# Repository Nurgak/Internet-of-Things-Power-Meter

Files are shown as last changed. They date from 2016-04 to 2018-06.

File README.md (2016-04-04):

# Internet-of-Things Power Meter

The Internet-of-Things Power Meter (IPM) is a device fixed on top of the regular household power meter and provides detailed information about the electricity usage. Modern power meters have a LED blinking every time a Watt is used, the IPM detects these flashes using a light sensor, counts them and saves the values to an SD card. Later the data is stored on the cloud.

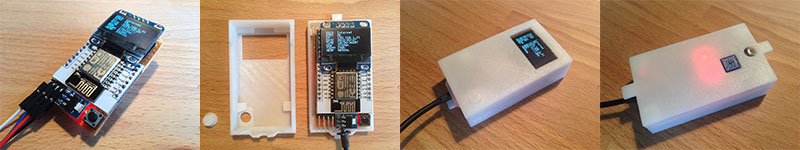
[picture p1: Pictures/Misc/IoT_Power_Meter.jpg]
IoT Power Meter development version on a breadboard


Usually power companies provide very rough electricity usage data, the IPM provides data with a minute resolution. Knowing the household electricity usage allows to extrapolate statistics and can give precise numbers about the costs.

The IPM was made with simplicity of assembly and cost in mind. The device is easy to build, program and cheap to deploy and use. One can basically buy the parts, assemble, program and deploy it without any knowledge about the inner workings, however contribution to the development of this open-source project is welcome and encouraged.

This is the second iteration of the electricity usage monitor project, the [first version can be seen here](https://github.com/Nurgak/Electricity-usage-monitor).

# Documentation

During development the IPM project is [documented on hackaday.io](https://hackaday.io/project/6938-internet-of-things-power-meter).

# License

The software is licensed under [GNU General Public License](https://en.wikipedia.org/wiki/GNU_General_Public_License).

The hardware is licensed under [Creative Commons Attribution-ShareAlike 4.0 International License](http://creativecommons.org/licenses/by-sa/4.0/).



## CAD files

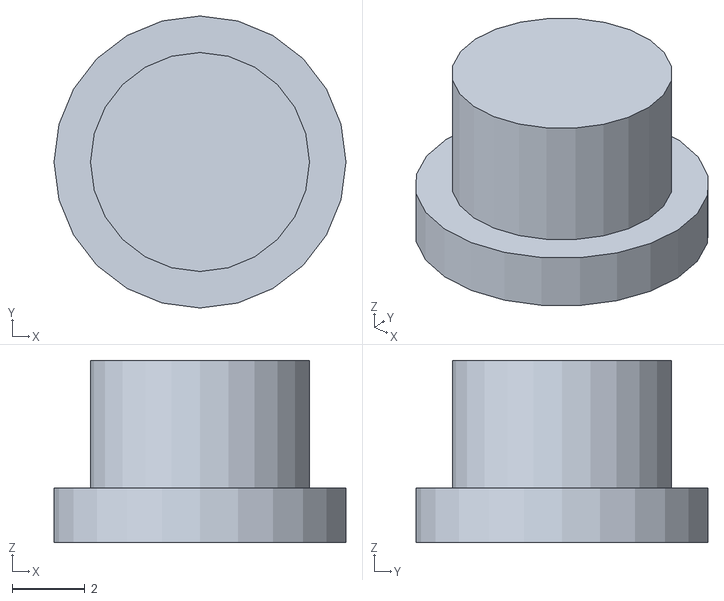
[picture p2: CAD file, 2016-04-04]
Hardware/Enclosure/IPM_Enclosure_button.stl
8.00 x 8.00 x 5.00

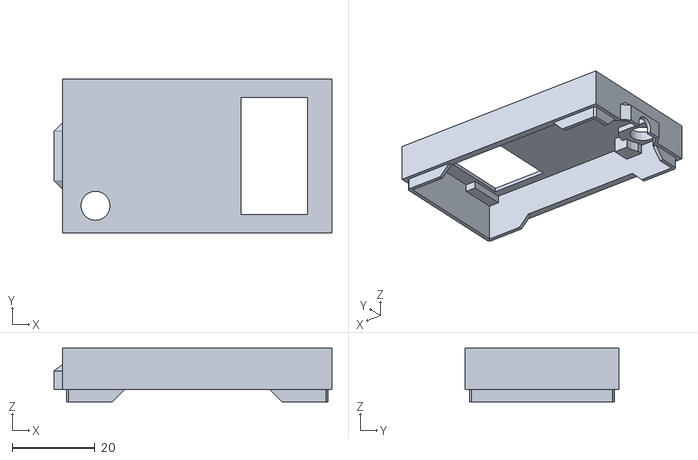
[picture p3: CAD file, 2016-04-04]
Hardware/Enclosure/IPM_Enclosure_top.stl
67.0 x 37.0 x 13.0

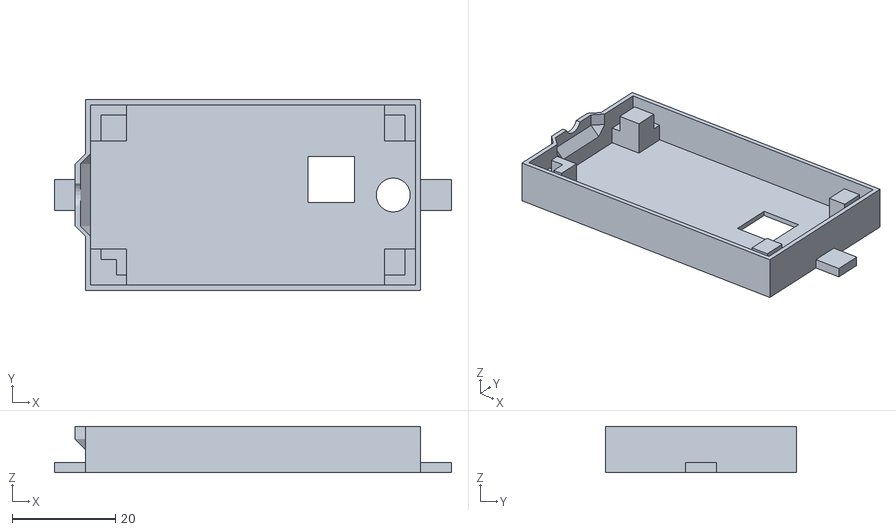
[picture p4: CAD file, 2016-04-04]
Hardware/Enclosure/IPM_Enclosure_bottom.stl
77.0 x 37.0 x 9.00

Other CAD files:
Hardware/Enclosure/IPM_Enclosure.skp

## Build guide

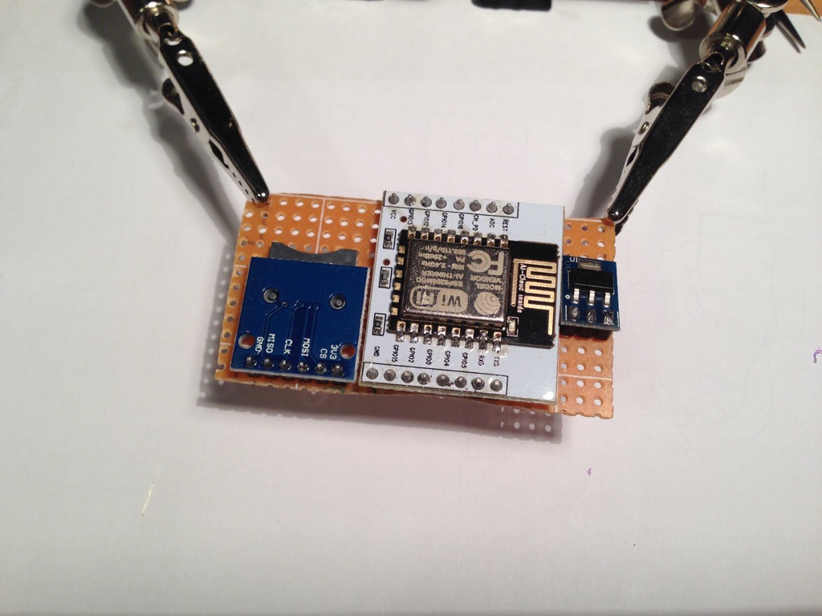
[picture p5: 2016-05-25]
Pictures/Build/2015-12-23 22.54.03.jpg

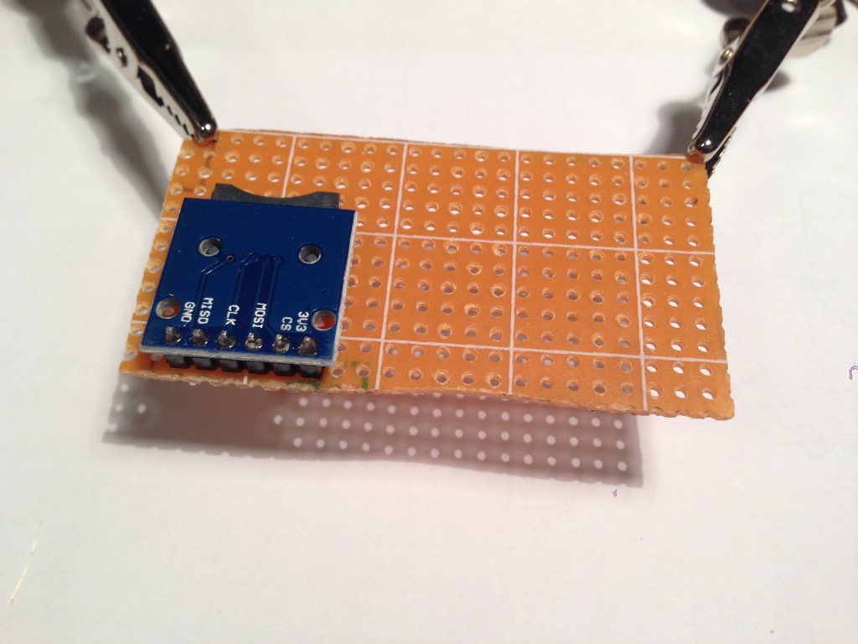
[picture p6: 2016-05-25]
Pictures/Build/2015-12-23 22.53.06.jpg

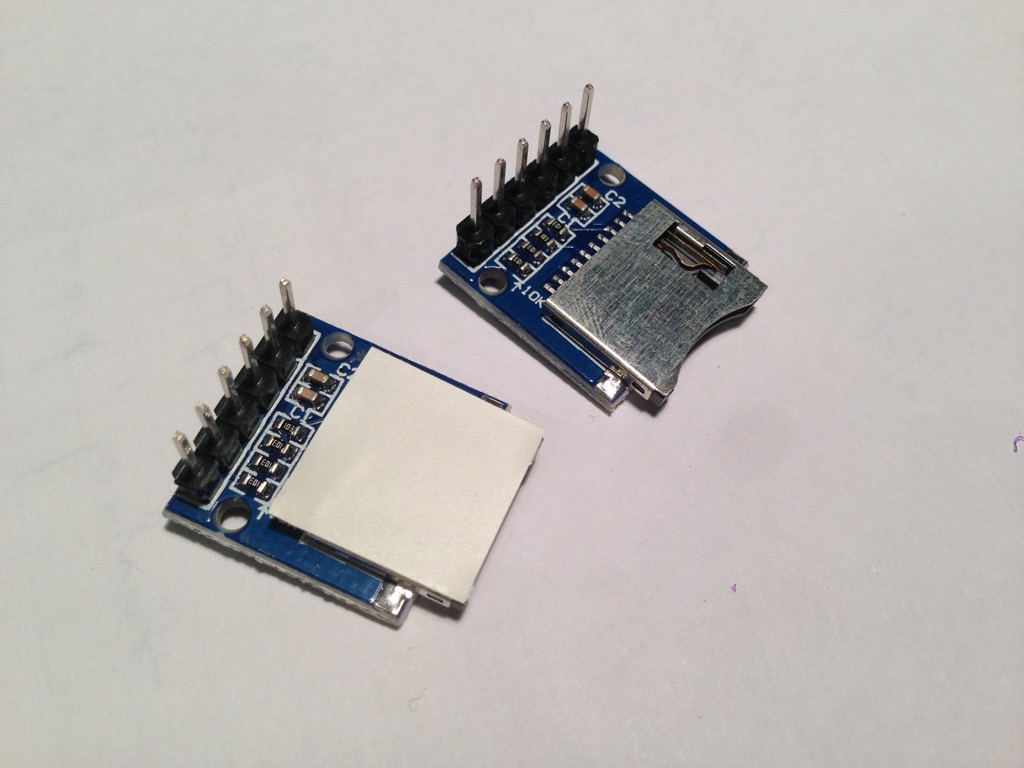
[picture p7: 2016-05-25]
Pictures/Build/2015-12-24 00.51.13.jpg

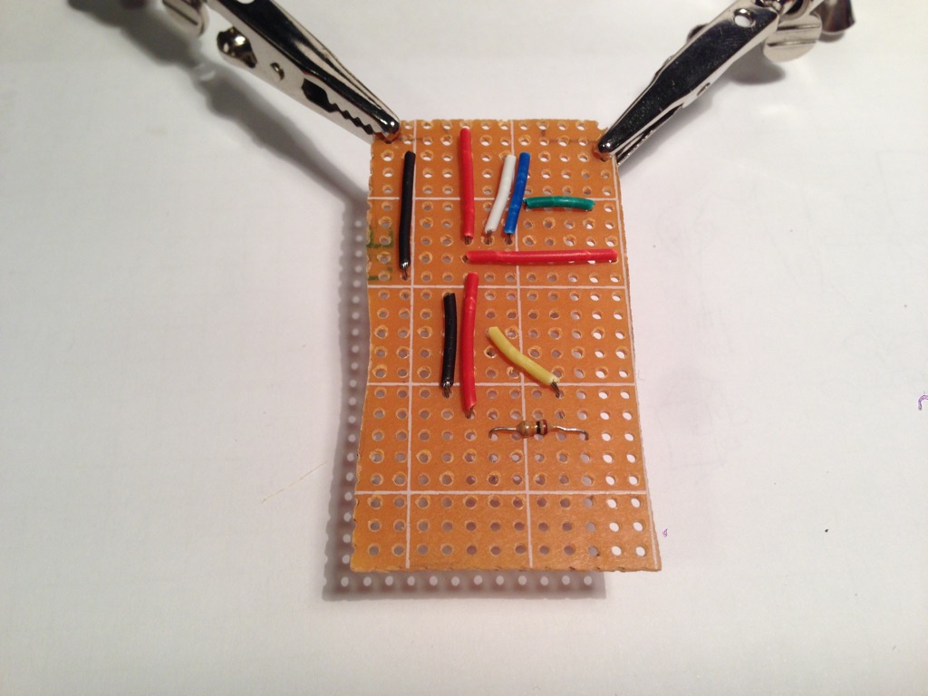
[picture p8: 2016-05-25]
Pictures/Build/2015-12-23 23.28.28.jpg

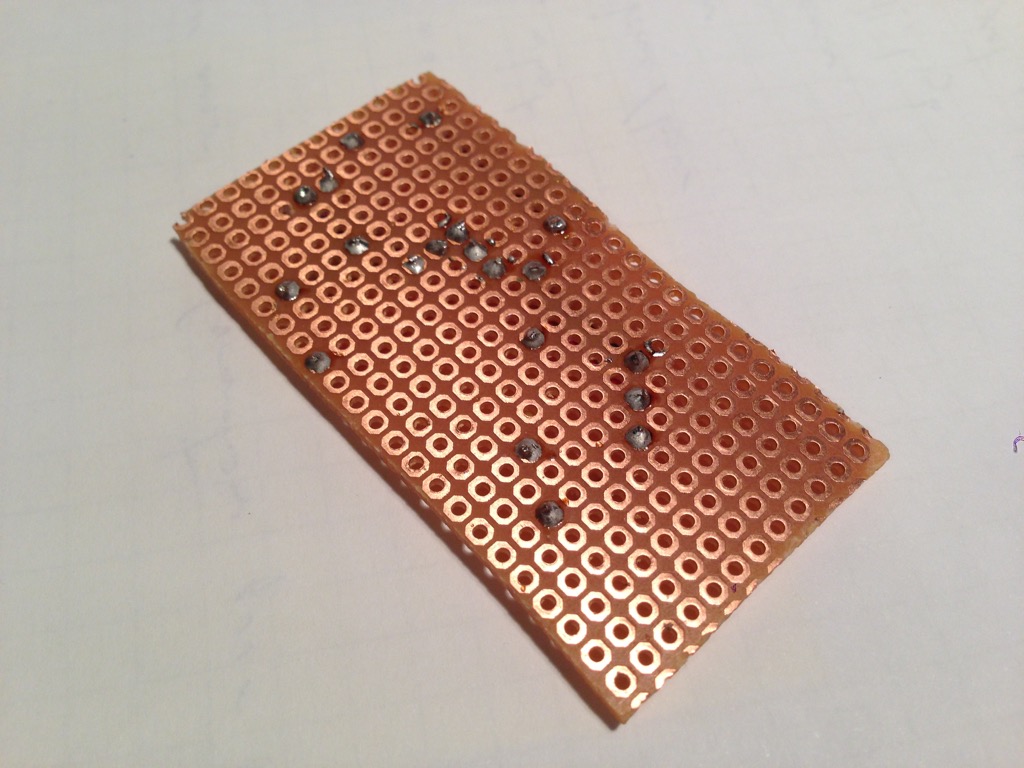
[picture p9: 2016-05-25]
Pictures/Build/2015-12-23 23.42.06.jpg

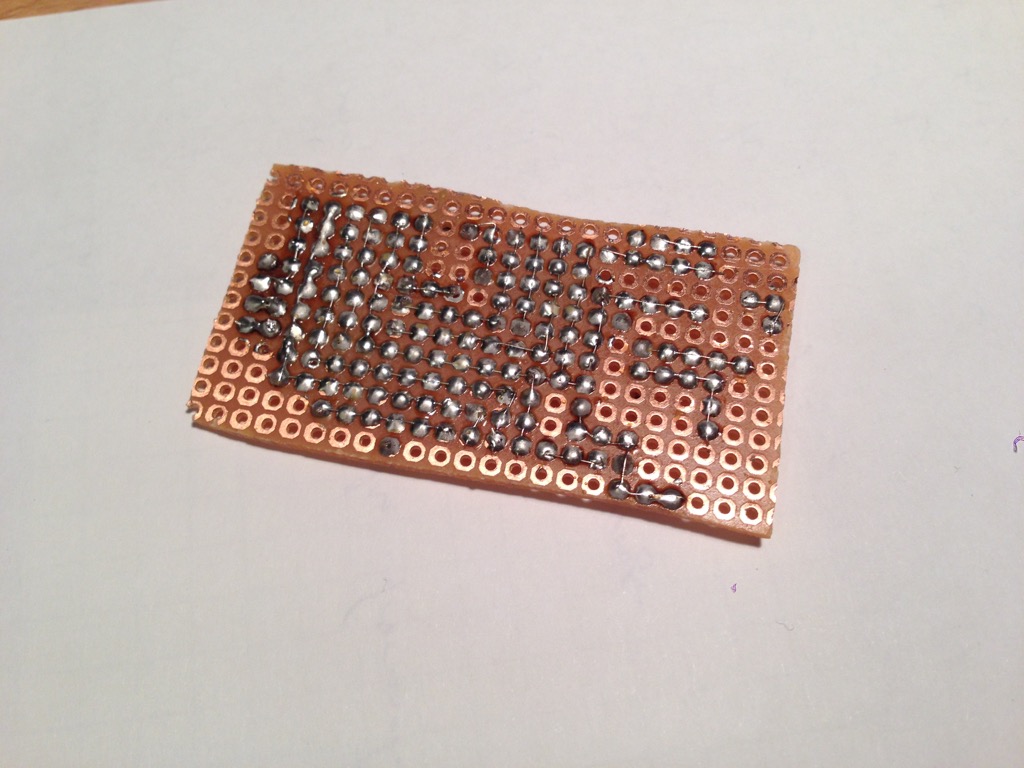
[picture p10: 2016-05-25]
Pictures/Build/2015-12-24 00.49.49.jpg

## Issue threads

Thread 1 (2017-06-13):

Row change in same date

lutfisan, 2017-06-13:
i try your IPM google script, but the row change in same date
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

this is my code
```
// Spreadsheet that is holding all the data
var SPREADSHEET_ID = "****";
var TIMEZONE = "Asia/Jakarta";
// Daylight savings time is not applied when this form is used:
//var TIMEZONE = "GMT+1";
// Secret token to make sure nobody else can submit data, even if the URL is disclosed
var TOKEN = "aku";

function doGet(e)
{
  return handleResponse(e);
}

function doPost(e)
{
  return handleResponse(e);
}

function handleResponse(e)
{
  // Extract the GET paramaters
  var data = e.parameter;
  // Dummy data for testing
  //var data = {"time": "1464339114", "power": "1234", "token": "SECRET_TOKEN"};

  // Make sure all data is passed
  if(!data.time || !data.power || !data.token)
  //if(!data.time || !data.power)
  {
    return ContentService.createTextOutput("Missing data");
  }

  // Make sure the data is valid, only numbers for time and power and only characters [a-zA-Z_0-9] for the token
  if(!data.time.match(/^\d+$/) || !data.power.match(/^\d+$/) || !data.token.match(/^\w+$/))
  //if(!data.time.match(/^\d+$/) || !data.power.match(/^\d+$/))
  {
    return ContentService.createTextOutput("Incorrect data");
  }

  // Make sure the token corresponds
  if(data.token != TOKEN)
  {
    return ContentService.createTextOutput("Wrong token");
  }

  var spreadsheet = getSpreadsheet(SPREADSHEET_ID);
  if(!spreadsheet)
  {
    return ContentService.createTextOutput("Spreadsheet not found");
  }

  // Open the day sheet
  var sheetDay = getSheet(spreadsheet, "Day");
  if(!sheetDay)
  {
    return ContentService.createTextOutput("Sheet not found");
  }

  insertData(sheetDay, data.time, data.power);

  return HtmlService.createHtmlOutput("OK");
}

function getSpreadsheet(id)
{
  // Open the spreadsheet
  var spreadsheet = SpreadsheetApp.openById(id);

  // Check that we got a spreadsheet
  if(!spreadsheet)
  {
    return false;
  }

  return spreadsheet;
}

function getSheet(spreadsheet, name)
{
  // Open the sheet
  var sheetDay = spreadsheet.getSheetByName(name);

  // Check that we got a sheet
  if(!sheetDay)
  {
    return false;
  }

  return sheetDay;
}

function insertData(sheet, timeUnix, power)
{
  // Column IDs
  var columnNames = {"date": 1, "power": 2, "cost": 3, "data": 4};

  // Time is passed in UNIX timestamp format in seconds, JavaScript wants milliseconds
  var date = new Date(timeUnix * 1000);

  // This allows to get the local time with timezone and DST
  var dateFormatted = Utilities.formatDate(date, TIMEZONE, "yyyy-MM-dd");
  // Make the hours an actual integer
  var hourFormatted = parseInt(Utilities.formatDate(date, TIMEZONE, "H"));

  // Define an invalid row number
  var rowId = -1;

  // Start from the row after the header (frozen rows)
  var startRow = sheet.getFrozenRows() + 1;

  // Check if there is already a row with the given date, skip the top header rows
  var days = sheet.getRange('A' + startRow +':A').getValues();

  for(var i in days)
  {
    // If the cell is empty then there is no point to go on
    if(days[i] == "")
    {
      // Stop scanning all the empty rows
      break;
    }

    // If the date matches then use that row
    // Use the "yyyy-MM-dd" format as parsing day month and year made it update the wrong day when the day changed for some reason
    // The timezone variable does not matter for a date parsed from "yyyy-MM-dd" format
    var dayFormatted = Utilities.formatDate(new Date(days[i]), 0, "yyyy-MM-dd");

    if(dateFormatted == dayFormatted)
    {
      // Skip the header row
      rowId = parseInt(i) + startRow;
      break;
    }
  }

  // No row with the same date was found
  if(rowId == -1)
  {
    // Since getLastRow() returns the value of the last non-empty row the value has to be increased manually (+1)
    rowId = sheet.getLastRow() + 1;

    // Update the date cell
    sheet.getRange(rowId, columnNames.date).setValue(dateFormatted);

    // Update sum formula for the total day power usage
    sheet.getRange(rowId, columnNames.power).setFormula("=SUM(D" + rowId + ":" + rowId + ")");

    // If there are at least 7 days of data (minus the header row) the settings of the cells one week ago will be copied over (cost formula and background color)
    if(rowId - 7 > sheet.getFrozenRows())
    {
      // Update the cost formula using 7 rows before it (to get the same weekday) if it is a valid cell
      var cost = sheet.getRange(rowId - 7, columnNames.cost).getFormulaR1C1();
      sheet.getRange(rowId, columnNames.cost).setFormulaR1C1(cost);

      // Update the cell formatting (background color) using 7 rows before it
      var backgrounds = sheet.getRange(rowId - 7, columnNames.data, 1, 24).getBackgrounds();
      sheet.getRange(rowId, columnNames.data, 1, 24).setBackgrounds(backgrounds);
    }
  }

  // Only fill the cell when there is nothing in it, otherwise it might overwrite important data
  var cell = sheet.getRange(rowId, columnNames.data + hourFormatted);
  if(cell.getValue() == "")
  {
    cell.setValue(power);
  }
}

```

Nurgak, 2017-09-10:
Sorry for the late answer, the code might be a bit rough as I didn't take care of the edge cases that well. Try adding more than 7 rows and then running it again. Consider contributing fixes if you can.

Closed 2018-05-24.

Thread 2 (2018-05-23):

Refactoring with Node-RED and MQTT

c0zm0z, 2018-05-23:
Hello Nurgak,

i have testet your old IPM. I love how you write code.

Is there any updated code for "Refactoring with Node-RED and MQTT"
I am very interested in in. i have some small MQTT experience, but i have never used Node-RED before. It looks interesting.

Nurgak, 2018-06-02:
@c0zm0z I uploaded the MQTT version: https://github.com/Nurgak/Internet-of-Things-Power-Meter/tree/master/Software/IoTPowerMeterMQTT

Node-RED is something that can really tie everything together. Now I log the data in the Node-RED server instead of the device SD card (less parts and not risking of running out of space) or remotely to Google Spreadsheets. This ensures that even if there is no access to the internet the data is saved.

I've made another project that shows the power consumption thanks to Node-RED: https://github.com/Nurgak/IoT-RGB-LED-Matrix

dony71, 2019-02-01:
I read your article about node-red and mqtt below but don't understand how you create calculation in node-red
Would you mind to share how you configure this in node-red?
I couldn't find also icon output "instant power", "cost", etc

https://hackaday.io/project/6938-internet-of-things-power-meter/log/66881-refactoring-with-node-red-
and-mqtt

Nurgak, 2019-02-02:
@dony71 The instant power is not calculated, you need to subscribe to the relevant MQTT topic. In the case of instant power the MQTT topic is defined as "powerCounterNow":
https://github.com/Nurgak/Internet-of-Things-Power-Meter/blob/e39c132d896e99e5e8b9e577e6842b63cb67a39d/Software/IoTPowerMeterMQTT/IoTPowerMeterMQTT.ino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

The "mqtt in" node configuration would look like this:
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

As far as the cost calculator goes I cannot really help, it depends on your provider tariffs and the model you have. In my case there is a _full price_ and _low price_ depending on the hour of the day and if it's a week-end. That makes a long function that is only relevant to me. Basically all I do it multiply the power cost by the instant usage and I get the instant cents/hour number, nothing really fancy.

dony71, 2019-02-03:
how about others like "power usage the last minute", "power usage the last hour", total "power usage over the day" ?
also i notice there is function extract power for each of them? what is this function equation?

Closed 2018-06-02.

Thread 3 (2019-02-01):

compilation error

dony71, 2019-02-01:
for the software, I follow this link  below
https://hackaday.io/project/6938-internet-of-things-power-meter/log/35131-show-me-the-source-code

while compile, I have this error below
I'm new in this, any step I'm missing?

WARNING: Category 'LED' in library CHT16K33 LED Matrix Library is not valid. Setting to 'Uncategorized'
WARNING: Category 'Input' in library MechInputs is not valid. Setting to 'Uncategorized'
WARNING: Category 'Input' in library SerialSensors is not valid. Setting to 'Uncategorized'
Build options changed, rebuilding all
F:\Users\xxx\Documents\GitHub\Internet-of-Things-Power-Meter\Software\IoTPowerMeter\IoTPowerMeter.ino:32:21: fatal error: TimeLib.h: No such file or directory
 #include <TimeLib.h>
                     ^
compilation terminated.

dony71, 2019-02-01:
i manage to get "timelib.h" from here https://github.com/PaulStoffregen/Time/blob/master/TimeLib.h
compiled OK

Closed 2019-02-01.

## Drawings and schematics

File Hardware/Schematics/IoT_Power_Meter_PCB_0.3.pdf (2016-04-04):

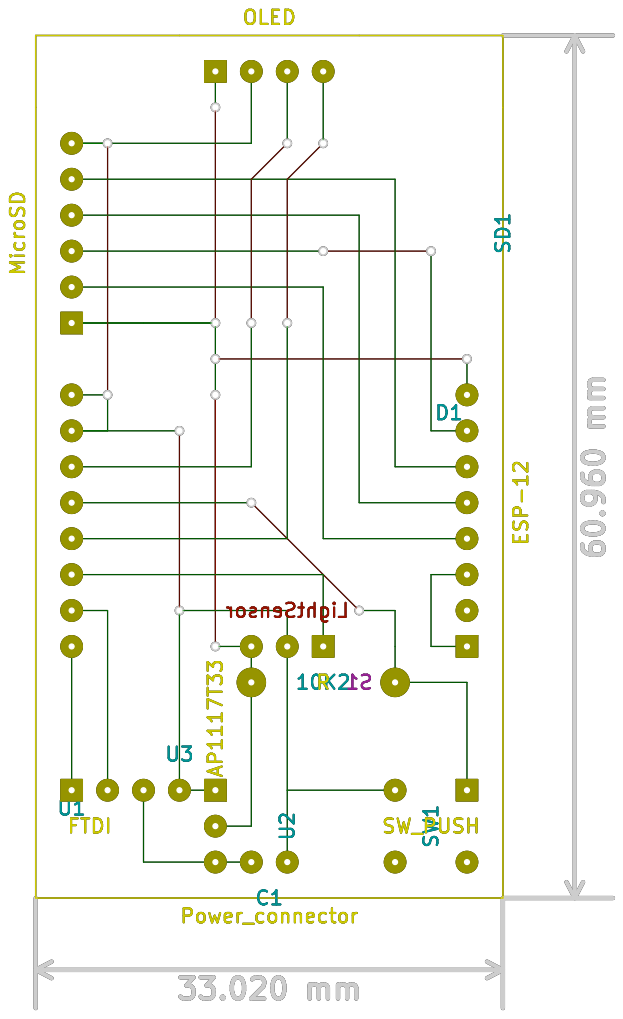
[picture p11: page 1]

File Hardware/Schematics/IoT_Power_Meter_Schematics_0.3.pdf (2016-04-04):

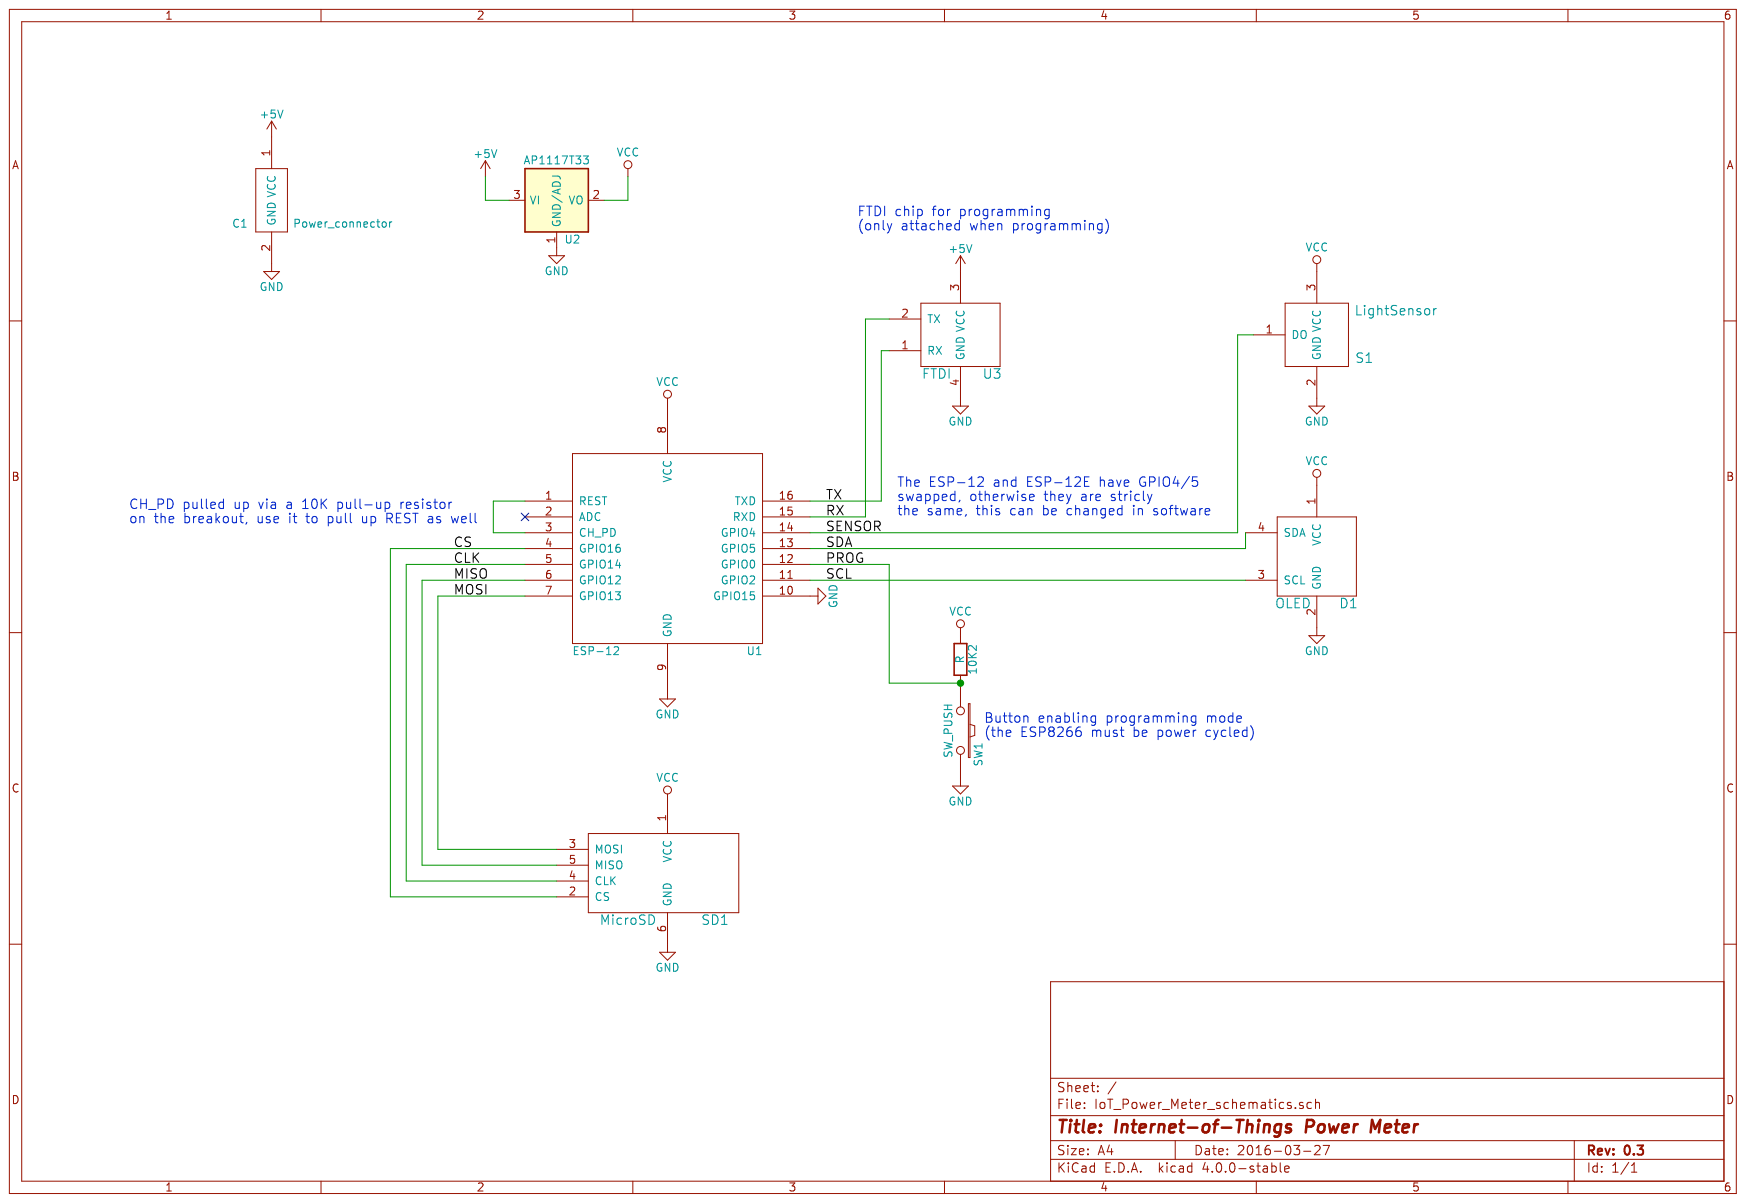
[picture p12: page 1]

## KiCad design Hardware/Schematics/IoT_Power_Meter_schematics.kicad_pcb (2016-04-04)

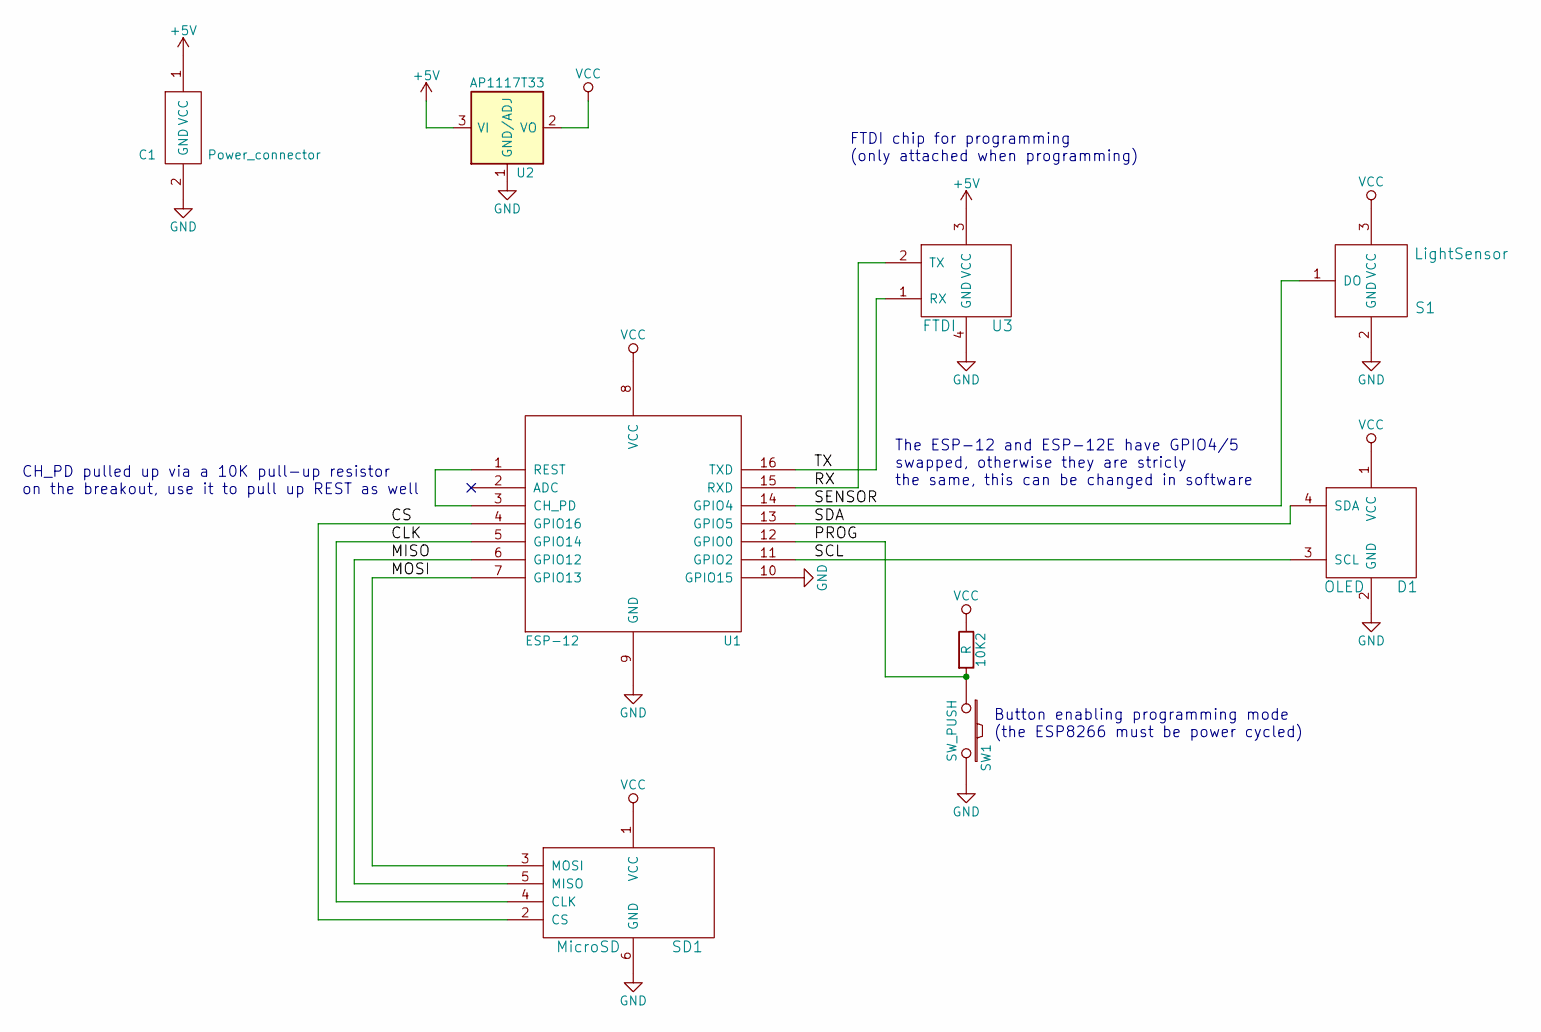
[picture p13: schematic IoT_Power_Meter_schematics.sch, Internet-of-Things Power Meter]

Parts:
10K2: R; Resistor_Horizontal_RM10mm
C1: Power_connector
D1: OLED
S1: LightSensor
SD1: MicroSD; uSD_card_reader
SW1: SW_PUSH; Button
U1: ESP-12; ESP8266-12E_breakout
U2: AP1117T33; 5-3V3_LDO
U3: FTDI

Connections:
+5V: C1.1 (VCC), U2.3 (VI), U3.3 (VCC)
/CLK: SD1.4 (CLK), U1.5 (GPIO14)
/CS: SD1.2 (CS), U1.4 (GPIO16)
/MISO: SD1.5 (MISO), U1.6 (GPIO12)
/MOSI: SD1.3 (MOSI), U1.7 (GPIO13)
/PROG: 10K2.2, SW1.1, U1.12 (GPIO0)
/RX: U1.15 (RXD), U3.2 (TX)
/SCL: D1.3 (SCL), U1.11 (GPIO2)
/SDA: D1.4 (SDA), U1.13 (GPIO5)
/SENSOR: S1.1 (DO), U1.14 (GPIO4)
/TX: U1.16 (TXD), U3.1 (RX)
GND: C1.2 (GND), D1.2 (GND), S1.2 (GND), SD1.6 (GND), SW1.2, U1.9 (GND), U1.10 (GPIO15), U2.1 (GND/ADJ), U3.4 (GND)
unnamed: U1.1 (REST), U1.3 (CH_PD)
VCC: 10K2.1, D1.1 (VCC), S1.3 (VCC), SD1.1 (VCC), U1.8 (VCC), U2.2 (VO)

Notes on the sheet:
Button enabling programming mode (the ESP8266 must be power cycled)
FTDI chip for programming (only attached when programming)
CH_PD pulled up via a 10K pull-up resistor on the breakout, use it to pull up REST as well
The ESP-12 and ESP-12E have GPIO4/5 swapped, otherwise they are stricly the same, this can be changed in software

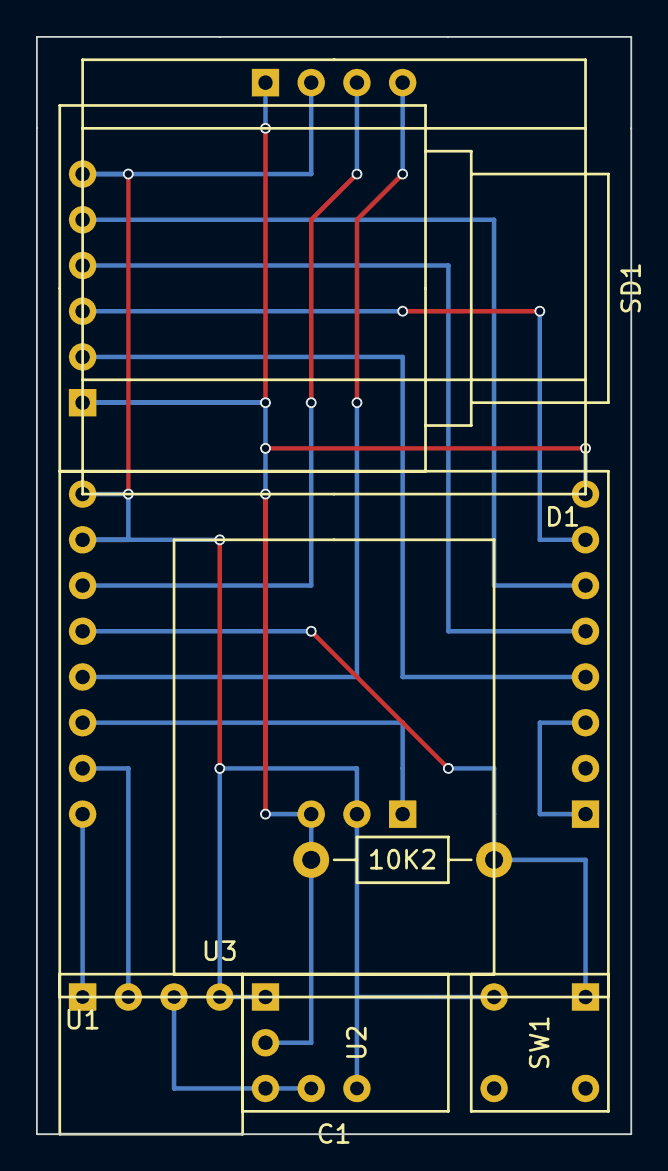
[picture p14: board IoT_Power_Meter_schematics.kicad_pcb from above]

Board: 2 copper layers, 33.0 x 61.0 mm, 9 parts (1 on the bottom side), 14 nets.

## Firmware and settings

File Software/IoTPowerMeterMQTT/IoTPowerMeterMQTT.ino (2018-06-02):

/*
  IoTPowerMeter - Software for the IoTPowerMeter based on the ESP8266

  Copyright (c) 2016 Karl Kangur. All rights reserved.
  This file is part of IoTPowerMeter.

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
  You should have received a copy of the GNU General Public License
  along with IoTPowerMeter.  If not, see <http://www.gnu.org/licenses/>.
*/

/*
 * File:    IoTPowerMeterMQTT.cpp
 * Author:  Karl Kangur <karl.kangur@gmail.com>
 * Licnece: GPL
 * URL:     https://github.com/Nurgak/Internet-of-Things-Power-Meter
 */

#include <ESP8266WiFi.h>
#include <ESP8266mDNS.h>
#include <TimeLib.h>
#include <Wire.h>
#include <ArduinoOTA.h>
#include <PubSubClient.h>

#include "config.h"
#include "IoTPowerMeterMQTT.h"
#include "ESP_SSD1306.h"

// Global instances
ESP_SSD1306 display;
WiFiClient espClient;
PubSubClient client(espClient);

// Global variables
static volatile uint16_t powerCounterMinute = 0;  // Counter used for logs
static volatile uint16_t powerCounterNow    = 0;  // Counter used for display
static volatile uint16_t powerCounterToday  = 0;  // Counter used for display
static volatile uint16_t powerCounterHour   = 0;  // Counter used for upload

// State transition matrix
const transition_t state_transitions[] = {
  {state_wifi_connect,   OK,   state_ota},
  {state_wifi_connect,   BUSY, state_display_update},
  {state_wifi_connect,   FAIL, state_display_update},
  {state_ota,            OK,   state_time_sync},
  {state_time_sync,      OK,   state_mqtt},
  {state_time_sync,      BUSY, state_display_update},
  {state_time_sync,      FAIL, state_display_update},
  {state_mqtt,           OK,   state_log},
  {state_mqtt,           BUSY, state_mqtt},
  {state_log,            OK,   state_display_update},
  {state_log,            BUSY, state_log},
  {state_log,            FAIL, state_display_update},
  {state_display_update, OK,   state_button_check},
  {state_button_check,   OK,   state_wifi_connect}
};

#define START_STATE state_wifi_connect

void setup(void)
{
  // See config.h file to enable/disable debugging
  #ifdef DEBUG_SERIAL
  DEBUG_SERIAL.begin(DEBUG_BAUDRATE);
  DEBUG_SERIAL.setDebugOutput(true);
  #endif

  // Initialise the screen and load a dummy screen
  display.begin();
  display.blank();

  // Define time syncing periodicity
  setSyncInterval(TIME_SYNC_PERIOD);

  // Attach the interrupt that counts the used Watts
  attachInterrupt(SENSOR_PIN, interrupt_blink, FALLING);
  
  // Show the new firmware upload progress on the display in percent
  ArduinoOTA.onProgress([](unsigned int progress, unsigned int total)
  {
    char buffer[16] = {0};
    sprintf(buffer, "Update: %d%%", (100 * progress / total));
    helper_set_status(buffer);
  });

  // Start the Over-The-Air update process
  ArduinoOTA.setHostname(hostName);
  ArduinoOTA.begin();
}

void loop()
{
  // Pointer to current state function, start with wifi connect
  static STATUS (*current_state)(void) = NULL;
  static STATUS code;
  static const size_t transitions = sizeof(state_transitions) / sizeof(state_transitions[0]);
  static size_t i;

  // Run the state machine
  for(i = 0; i < transitions; i++)
  {
    if(state_transitions[i].state_source == current_state && state_transitions[i].code == code)
    {
      current_state = state_transitions[i].state_destination;
      // Call the state function, get the return code back for next transition
      code = (current_state)();
      // Return immediately
      return;
    }
  }

  // Exception: no transition from state was found, start again
  current_state = START_STATE;
}

STATUS ICACHE_FLASH_ATTR state_wifi_connect()
{
  static STATUS wifi_connect_status = FAIL;
  static uint32_t time_wifi_connect = 0;
  static bool wifi_configured = false;

  // If connected and configuration is correct return immediately
  if(wifi_configured && WiFi.status() == WL_CONNECTED)
  {
    if(wifi_connect_status != OK)
    {
      helper_set_status("OK");
      time_wifi_connect = 0;
      
      client.setServer(mqtt_server, mqtt_port);
  
      wifi_connect_status = OK;
    }
  }
  else if(wifi_connect_status == BUSY)
  {
    if(millis() - time_wifi_connect > TIME_WIFI_CONNECT)
    {
      time_wifi_connect = 0;
      wifi_configured = false;
      wifi_connect_status = FAIL;
    }
    else
    {
      wifi_connect_status = BUSY;
    }
  }
  else
  {
    // Calling WiFi.begin disconnects and prevents the module from connecting
    WiFi.begin(wifi_ssid, wifi_password);

    // Without this the WiFi might connect too fast using an old configuration
    wifi_configured = true;

    // Required to get mDNS working
    MDNS.begin(hostName);

    helper_set_status("Connecting");
    time_wifi_connect = millis();
    wifi_connect_status = BUSY;
  }

  return wifi_connect_status;
}

STATUS ICACHE_FLASH_ATTR state_ota()
{
  // Handle OTA updates
  ArduinoOTA.handle();

  // This state can only return true, the particular cases are taken care by OTA
  // callbacks (start, progress, end...) which must be defined in the setup
  return OK;
}

STATUS ICACHE_FLASH_ATTR state_time_sync()
{
  // Internal time sync state
  static STATUS time_sync_status = FAIL;
  static WiFiUDP udp;
  static byte packetBuffer[NTP_PACKET_SIZE] = {0};
  // Time when the request was started
  static uint32_t time_request = 0;

  // Time can be set, unset or in need of synchronisation modes
  if(timeStatus() == timeSet)
  {
    time_sync_status = OK;
  }
  else if(time_sync_status == BUSY)
  {
    if(udp.parsePacket())
    {
      // Read packet to buffer
      udp.read(packetBuffer, NTP_PACKET_SIZE);

      // Only bytes 40 to 43 are important, trash the rest
      // Concatenate 4 bytes and remove 70 years since Unix time starts on Jan 1 1970 and we want 1900
      time_t currentTime = ((packetBuffer[40] << 24) | (packetBuffer[41] << 16) | (packetBuffer[42] << 8) | packetBuffer[43]) - 2208988800UL;
      setTime(currentTime);

      // Stop and release the resources
      udp.stop();
      // Time has been synchronised with server, return OK
      helper_set_status("OK");
      time_request = 0;
      time_sync_status = OK;
    }
    else if(millis() - time_request > TIME_SYNC_RESPONSE)
    {
      // Stop and release the resources
      udp.stop();
      // Waited for too long for time sync
      helper_set_status("Time error");
      time_request = 0;
      time_sync_status = FAIL;
    }
    else
    {
      time_sync_status = BUSY;
    }
  }
  else
  {
    helper_set_status("Time sync");

    // Synchronise local time with an Network Time Protocol (NTP) server
    IPAddress timeServerIP;

    udp.begin(2390);

    // Get the IP from the address
    WiFi.hostByName(ntpServerName, timeServerIP);

    // Send an NTP packet to a time server
    memset(packetBuffer, 0, NTP_PACKET_SIZE);

    packetBuffer[0] = 0b11100011;  // LI, Version, Mode
    packetBuffer[1] = 0;           // Stratum, or type of clock
    packetBuffer[2] = 6;           // Polling Interval
    packetBuffer[3] = 0xEC;        // Peer Clock Precision
    // 8 bytes of zero for Root Delay & Root Dispersion
    packetBuffer[12] = 49;
    packetBuffer[13] = 0x4E;
    packetBuffer[14] = 49;
    packetBuffer[15] = 52;

    // Send the packet to port 123 of the NTP server
    udp.beginPacket(timeServerIP, 123);
    udp.write(packetBuffer, NTP_PACKET_SIZE);
    udp.endPacket();

    memset(packetBuffer, 0, NTP_PACKET_SIZE);
    time_request = millis();
    time_sync_status = BUSY;
  }

  return time_sync_status;
}

STATUS ICACHE_FLASH_ATTR state_mqtt()
{
  if(!client.connected())
  {
    if(client.connect(hostName))
    {
      // Subscribe to topics here
    }
    return BUSY;
  }
  client.loop();
  
  return OK;
}

STATUS ICACHE_FLASH_ATTR state_log()
{
  // Start logging at the beginning of the next minute/hour
  static uint8_t currentHour = hour();
  static uint8_t currentMinute = minute();
  static uint16_t powerCounterHourTemp = 0;
  static uint16_t powerCounterMinuteTemp = 0;
  static bool fileRemoved = false;

  if(minute() != currentMinute)
  {
    helper_set_status("Logging");

    // TODO These two lines should be atomic, a blink might occur between them
    powerCounterMinuteTemp = powerCounterMinute;
    powerCounterMinute = 0;

    // Remove 60 seconds as data is valid for the previous minute
    time_t timestamp = now() - 60;
    uint16_t minuteOfTheDay = hour(timestamp) * 60 + minute(timestamp);
    char data[16];
    sprintf(data, "%d,%d\n", minuteOfTheDay, powerCounterMinuteTemp);
    client.publish("powerCounterMinute", data);

    currentMinute = minute();

    // Publish the hour counter every new hour (Wh)
    if(hour() != currentHour)
    {
      powerCounterHourTemp = powerCounterHour;
      // Reset the counter for the next hour
      powerCounterHour = 0;

      // Clear the buffer
      memset(data, 0, sizeof(data));
      sprintf(data, "%d,%d\n", hour(timestamp), powerCounterHourTemp);
      client.publish("powerCounterHour", data);

      currentHour = hour();
    }

    // Logging successful
    helper_set_status("OK");
  }

  return OK;
}

STATUS ICACHE_FLASH_ATTR state_button_check()
{
  // Detect short and long button presses by polling the button pin
  static uint32_t button_hold_time = 0;
  if(digitalRead(BUTTON_PIN) == LOW && button_hold_time == 0)
  {
    // Button was pressed and the button hold timer was 0, start counter
    button_hold_time = millis();
  }
  else if(digitalRead(BUTTON_PIN) == HIGH && button_hold_time != 0)
  {
    if(millis() - button_hold_time > TIME_BUTTON_PRESS_LONG)
    {
      // Button was held down for TIME_BUTTON_PRESS_LONG milliseconds or more
      helper_button_long();
    }
    else if(millis() - button_hold_time > TIME_BUTTON_PRESS_SHORT)
    {
      // Button was released before TIME_BUTTON_PRESS_LONG milliseconds
      helper_button_short();
    }

    // Reset counter
    button_hold_time = 0;
  }

  return OK;
}

// Update data on screen
STATUS ICACHE_FLASH_ATTR state_display_update()
{
  static char buffer[16] = {0};

  // Initilise with invalid values so they are updated right away
  static uint8_t currentSecond = 0xff;
  static uint8_t currentDay = 0xff;
  static uint16_t powerCounterNowTemp = 0;
  static uint16_t powerCounterTodayTemp = 0;
  static uint32_t heapTemp = 0;
  static uint32_t sizeTemp = 0;
  static IPAddress ip;

  if(ip != WiFi.localIP())
  {
    ip = WiFi.localIP();
    memset(buffer, 0, sizeof(buffer));
    sprintf(buffer, "%d.%d.%d.%d", ip[0], ip[1], ip[2], ip[3]);
    display.clear(SCREEN_ROW_IP, SCREEN_START_COLUMN);
    display.sendStrXY(buffer, SCREEN_ROW_IP, SCREEN_START_COLUMN);
  }

  // Auto-update date if day has changed
  if(currentDay != day())
  {
    currentDay = day();
    memset(buffer, 0, sizeof(buffer));
    sprintf(buffer, "%04d-%02d-%02d", year(), month(), currentDay);
    display.clear(SCREEN_ROW_DATE, SCREEN_START_COLUMN);
    display.sendStrXY(buffer, SCREEN_ROW_DATE, SCREEN_START_COLUMN);
    // Reset today power counter upon day change
    powerCounterToday = 0;
  }

  // Auto-update time if second has changed
  if(currentSecond != second())
  {
    currentSecond = second();
    memset(buffer, 0, sizeof(buffer));
    sprintf(buffer, "%02d:%02d:%02dUTC", hour(), minute(), currentSecond);
    display.clear(SCREEN_ROW_TIME, SCREEN_START_COLUMN);
    display.sendStrXY(buffer, SCREEN_ROW_TIME, SCREEN_START_COLUMN);
  }

  // Auto-update current power counter if it has changed

  if(powerCounterNow != powerCounterNowTemp)
  {
    powerCounterNowTemp = powerCounterNow;
    memset(buffer, 0, sizeof(buffer));
    sprintf(buffer, "%dW", powerCounterNowTemp);
    display.clear(SCREEN_ROW_NOW, SCREEN_START_COLUMN);
    display.sendStrXY(buffer, SCREEN_ROW_NOW, SCREEN_START_COLUMN);

    // Publish the counter via MQTT
    client.publish("powerCounterNow", buffer);
  }

  // Auto-update day power counter if it has changed
  if(powerCounterToday != powerCounterTodayTemp)
  {
    powerCounterTodayTemp = powerCounterToday;
    memset(buffer, 0, sizeof(buffer));
    sprintf(buffer, "%dWh", powerCounterTodayTemp);
    display.clear(SCREEN_ROW_TODAY, SCREEN_START_COLUMN);
    display.sendStrXY(buffer, SCREEN_ROW_TODAY, SCREEN_START_COLUMN);
    
    // Publish the counter via MQTT
    client.publish("powerCounterToday", buffer);
  }

  // Auto-update the heap size information if it has changed
  if(heapTemp != ESP.getFreeHeap())
  {
    heapTemp = ESP.getFreeHeap();
    memset(buffer, 0, sizeof(buffer));
    sprintf(buffer, "%db", heapTemp);
    display.clear(SCREEN_ROW_HEAP, SCREEN_START_COLUMN);
    display.sendStrXY(buffer, SCREEN_ROW_HEAP, SCREEN_START_COLUMN);
  }

  return OK;
}

void ICACHE_FLASH_ATTR helper_button_short()
{
  helper_set_status("Short press");
  client.publish("powerCounterButton", "button press short");
}

void ICACHE_FLASH_ATTR helper_button_long()
{
  helper_set_status("Long press");
  client.publish("powerCounterButton", "button press long");
}

// Show the current action in the STAT field on the screen
void ICACHE_FLASH_ATTR helper_set_status(const char * status)
{
  display.clear(SCREEN_ROW_STAT, SCREEN_START_COLUMN);
  display.sendStrXY(status, SCREEN_ROW_STAT, SCREEN_START_COLUMN);
}

// Blink interrupt, called every time the LED blinks
void ICACHE_FLASH_ATTR interrupt_blink()
{
  static uint32_t timeBlinkLast = 0;
  static uint32_t timeBlinkCurrent = 0;

  // Debounce routine, because sometimes one LED blink gets detected multiple times
  // This is millis() rollover safe as (millis() - timeBlinkCurrent) is never negative
  if((uint32_t)(millis() - timeBlinkLast) < TIME_DEBOUNCE)
  {
    // Do not accept blinks more often than TIME_DEBOUNCE (milliseconds)
    return;
  }

  // Update the power counters
  powerCounterMinute++;
  powerCounterHour++;
  powerCounterToday++;

  // Avoid dividing by zero (crashes the program otherwise)
  timeBlinkCurrent = millis();
  if(timeBlinkCurrent != timeBlinkLast)
  {
    // Evaluate the current power consumption 60 seconds * 60 minutes * 1000 milliseconds = h
    powerCounterNow = 60 * 60 * 1000 / (timeBlinkCurrent - timeBlinkLast);
  }
  timeBlinkLast = timeBlinkCurrent;
}

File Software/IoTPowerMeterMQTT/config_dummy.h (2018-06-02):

/*
  IoTPowerMeter - Software for the IoTPowerMeter based on the ESP8266

  Copyright (c) 2016 Karl Kangur. All rights reserved.
  This file is part of IoTPowerMeter.

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
  You should have received a copy of the GNU General Public License
  along with IoTPowerMeter.  If not, see <http://www.gnu.org/licenses/>.
*/

/*
 * File:    config_dummy.h
 * Author:  Karl Kangur <karl.kangur@gmail.com>
 * Licnece: GPL
 * URL:     https://github.com/Nurgak/Internet-of-Things-Power-Meter
 */

#ifndef CONFIG_H
#define CONFIG_H

/*** WARNING: ESP-12 and ESP-12E have their GPIO4/5 swapped, so define the correct pins here ***/

// Light sensor pin (do not use GPIO16, it cannot do interrupts)
#define SENSOR_PIN 5
// Button is used for entering programming mode or to toggle between functions (GPIO0)
#define BUTTON_PIN 0
// Chip select pin for the SD card reader
#define SD_CS_PIN 16
// Pin connected to the LED (serial TX)
#define LED_PIN 1
// I2C data and clock pins for the screen
#define PIN_SDA 4
#define PIN_SCL 2

// How often the internal time is synchronised with the NTP server
#define TIME_SYNC_PERIOD 12*60*60 // [s]
// NTP server from which to fetch the time
static const char * ntpServerName = "time.nist.gov";

#define ENABLE_INTERNET // Comment thus line to remove all internet related functionalities
static const char * wifi_ssid = "...";
static const char * wifi_password = "...";

// MQTT server configuration
static const char * mqtt_server = "192.168.1.3";
static const unsigned int mqtt_port = 1883;
static const char * hostName = "IoTPowerMeter";

// Global constants, no magic numbers
#define TIME_WIFI_CONNECT 5000 // Maximum waiting time in seconds for Wi-Fi connection
#define TIME_SYNC_RESPONSE 3000 // Maximum time the system will wait for a response from the NTP server (milliseconds)
#define TIME_BUTTON_PRESS_SHORT 100 // Time in milliseconds for the short button press routine to execute
#define TIME_BUTTON_PRESS_LONG 2000 // Time in milliseconds for the long button press routine to execute
#define TIME_DEBOUNCE 200 // Time in milliseconds during which LED blinks are ignored when one was just detected
#define SCREEN_TITLE_COLUMN 0 // Horizontal position from which the title should be displayed on screen
#define SCREEN_START_COLUMN 6 // Horizontal position from which the data should be displayed on screen
#define SCREEN_ROW_STAT  0
#define SCREEN_ROW_IP    1
#define SCREEN_ROW_DATE  2
#define SCREEN_ROW_TIME  3
#define SCREEN_ROW_NOW   4
#define SCREEN_ROW_TODAY 5
#define SCREEN_ROW_HEAP  6
#define NTP_PACKET_SIZE 48

// For debugging
/*#define DEBUG_SERIAL Serial
#define DEBUG_BAUDRATE 115200
#define DEBUGV(...) ets_printf(__VA_ARGS__)*/

#endif

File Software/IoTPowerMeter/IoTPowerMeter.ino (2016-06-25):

/*
  IoTPowerMeter - Software for the IoTPowerMeter based on the ESP8266

  Copyright (c) 2016 Karl Kangur. All rights reserved.
  This file is part of IoTPowerMeter.

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
*/

/*
 * File:    IoTPowerMeter.ino
 * Author:  Karl Kangur <karl.kangur@gmail.com>
 * Licnece: GPL
 * URL:     https://github.com/Nurgak/Internet-of-Things-Power-Meter
 */

#include <ESP8266WiFi.h>
#include <ESP8266WebServer.h>
#include <ESP8266mDNS.h>
#include <TimeLib.h>
#include <Wire.h>
#include <SPI.h>
#include <SD.h>

#include "config.h"
#include "IoTPowerMeter.h"
#include "ESP_SSD1306.h"
#include "server.h"
#include "push.h"

// Global instances
IPAddress ip;
ESP_SSD1306 display;

#if defined(ENABLE_INTERNET) && defined(PUSH_GOOGLE_SPREADSHEETS)
static GoogleSpreadsheets gs(googleSpreadSheetsScript);
#endif

// Global variables
static volatile uint16_t powerCounter          = 0;  // Internal counter [Wh]
static volatile uint16_t powerCounterNow       = 0;  // Instant power usage [Wh]
static volatile uint16_t powerCounterToday     = 0;  // Total day power usage [Wh]
static volatile uint8_t screenUpdateFieldFlags = 0;

void setup(void)
{
  // See config.h file to enable/disable debugging
  #ifdef DEBUG_SERIAL
  DEBUG_SERIAL.begin(DEBUG_BAUDRATE);
  DEBUG_SERIAL.setDebugOutput(true);
  #endif
  
  // Initialise the screen
  display.begin();
  
  // Load a dummy screen
  display.blank();
  
  #ifdef ENABLE_INTERNET
  // Try to connect to the access point (AP)
  if(WiFi.status() != WL_CONNECTED)
  {
    screenStatus("Connecting...");
    while(!setupWiFi())
    {
      screenStatus("WiFi error");
      ESP.restart();
      delay(1000);
    }
    screenStatus("Connected");
  }
  
  // Initialise the SD card
  if(!SD.begin(SD_CS_PIN))
  {
    screenStatus("No SD card");
    // Require a reset, inserting an SD card while in opertation does not work well
    while(1){};
  }
  
  initServer();
  
  // Set up the internal clock synchronizing function with a Network Time Protocol (NTP) server
  setSyncProvider(syncTime);
  setSyncInterval(TIME_SYNC_PERIOD);
  #else
  // Turn off WiFi
  WiFi.disconnect(true);
  #endif
  
  // Reset the counters on the screen
  screenUpdateFieldFlags |= TODAY | NOW;
  
  // Attach the interrupt that counts the used Watts
  attachInterrupt(SENSOR_PIN, blinkWatt, FALLING);
  // Attach the interrupt for the button press, attached to GPIO0
  // GPIO0 has an external pull-up 
  attachInterrupt(BUTTON_PIN, buttonPress, FALLING);
}

void loop(void)
{
  // Define and initialise with invalid values so they will get updated right away
  static uint8_t currentMinute = 0xff;
  static uint8_t currentDay = 0xff;
  static uint8_t currentHour = 0xff;
  static uint16_t powerCounterHour = 0; // Power counter for the current hour
  static uint16_t powerCounterHourTemp = 0; // Temporary variable for pushing data to the internet
  static uint16_t powerCounterTemp = 0; // Temporary variable for logging
  static bool uploadData = false; // Temporary variable indicating if data should be uploaded
  static char buffer[32]; // Buffer for log messages
  
  // Handle client connecting to server
  #ifdef ENABLE_INTERNET
  handleClient();
  #endif

  // A new minute has happened! Log, save and reset
  if(currentMinute != minute())
  {
    currentMinute = minute();
    
    // Log the last minute data to SD card
    // Copy the counter to a temporary variable and reset it
    // TODO: these actions should be atomic, a blink can potentially happen between these instructions and be lost
    powerCounterTemp = powerCounter;
    powerCounter = 0;

    // Cumulative hour counter to log data hourly
    powerCounterHour += powerCounterTemp;

    // Get the previous minute value by removing 60 seconds from current minute
    // Second precision does not matter
    time_t timeLogEntry = now() - 60;
    logData(timeLogEntry, powerCounterTemp);

    // Reset the today counter when the day changes
    if(day() != currentDay)
    {
      sprintf(buffer, "Day power usage: %dWh", powerCounterToday);
      logEvent(buffer);
      
      currentDay = day();
      powerCounterToday = 0;
    }

    // Hourly counter
    if(currentHour != hour())
    {
      currentHour = hour();
      powerCounterHourTemp = powerCounterHour;
      powerCounterHour = 0;
      
      // This is used to upload data hourly further down below, but it might take time so just set a flag here
      uploadData = true;
    }

    #ifdef ENABLE_INTERNET
    // Check that the device is still connected to the WiFi
    if(WiFi.status() != WL_CONNECTED)
    {
      screenStatus("Connecting...");
      if(!setupWiFi())
      {
        screenStatus("WiFi error");
      }
    }

    if(WiFi.status() == WL_CONNECTED)
    {
      // Try to sync time if it is unsychronised (invalid time)
      if(timeStatus() == timeNotSet)
      {
        // Will try to sync the time and set the appropriate state for timeStatus()
        setSyncProvider(syncTime);
      }
      
      #if defined(PUSH_GOOGLE_SPREADSHEETS)
      if(uploadData)
      {
        uploadData = false;
        
        // Try to push data to Google Spreadsheets
        screenStatus("Uploading data");
        
        // Try a couple of times
        uint8_t retries = MAX_TRIES_UPLOAD;
        boolean uploadComplete = false;
        while(retries--)
        {
          DEBUGV("Uploading data, try %d\n", MAX_TRIES_UPLOAD - retries);

          // For hourly logs the minutes are not important, but to be sure we have the right hour (the last one) remove 30 minutes (minus the 1 from before too) from now
          // This is because the data uploaded is for the last hour, not the current hour, the server will only keep the hour of the day, the minutes are irrelevant
          time_t timeLogHour = timeLogEntry - 30 * 60;
          if(gs.submit(timeLogHour, powerCounterHourTemp))
          {
            screenStatus("OK");
            
            uploadComplete = true;
            
            sprintf(buffer, "Data uploading tries: %d", MAX_TRIES_UPLOAD - retries);
            logEvent(buffer);
            
            break;
          }
        }

        if(!uploadComplete)
        {
          screenStatus("Upload failed");
          logEvent("Upload failed");
        }
      }
      #endif
    }
    #endif
  }
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

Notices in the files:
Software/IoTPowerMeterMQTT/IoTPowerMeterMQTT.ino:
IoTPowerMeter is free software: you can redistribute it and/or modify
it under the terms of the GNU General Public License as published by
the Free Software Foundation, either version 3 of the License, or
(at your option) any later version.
